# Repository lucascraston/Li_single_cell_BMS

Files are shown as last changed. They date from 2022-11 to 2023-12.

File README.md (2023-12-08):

# Li_single_cell_BMS

<p>
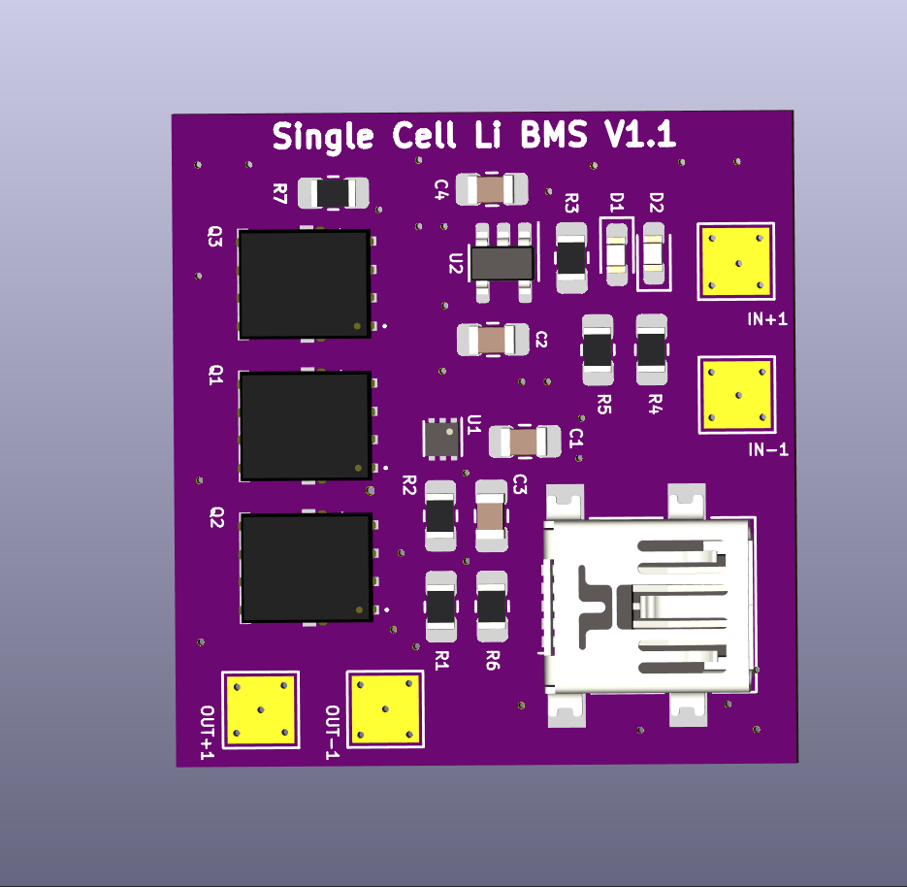
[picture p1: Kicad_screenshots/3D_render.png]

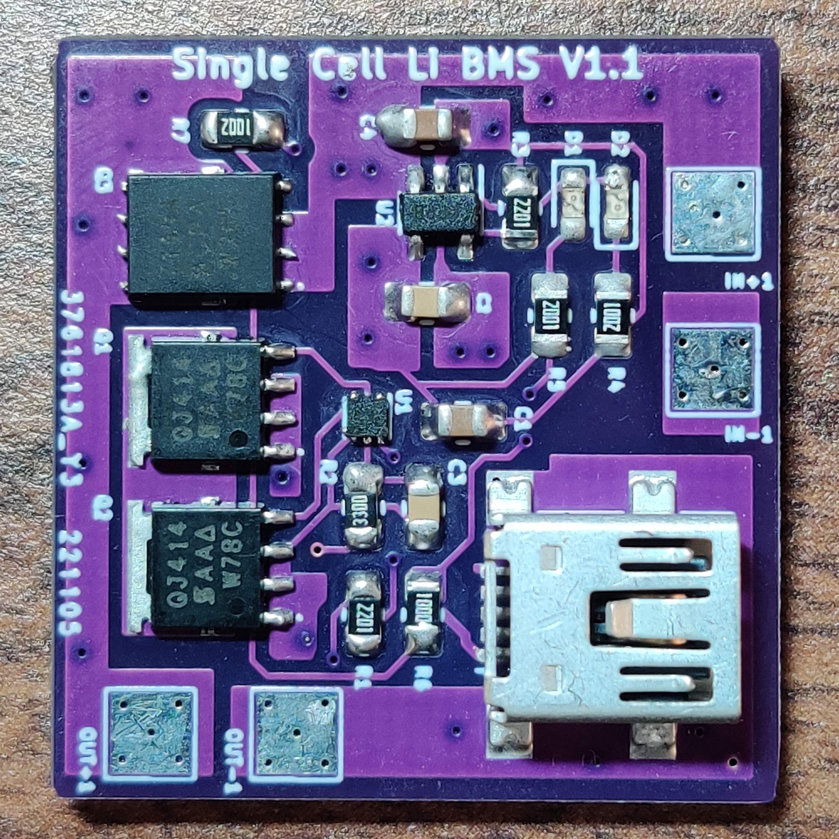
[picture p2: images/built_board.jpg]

</p>
<p>
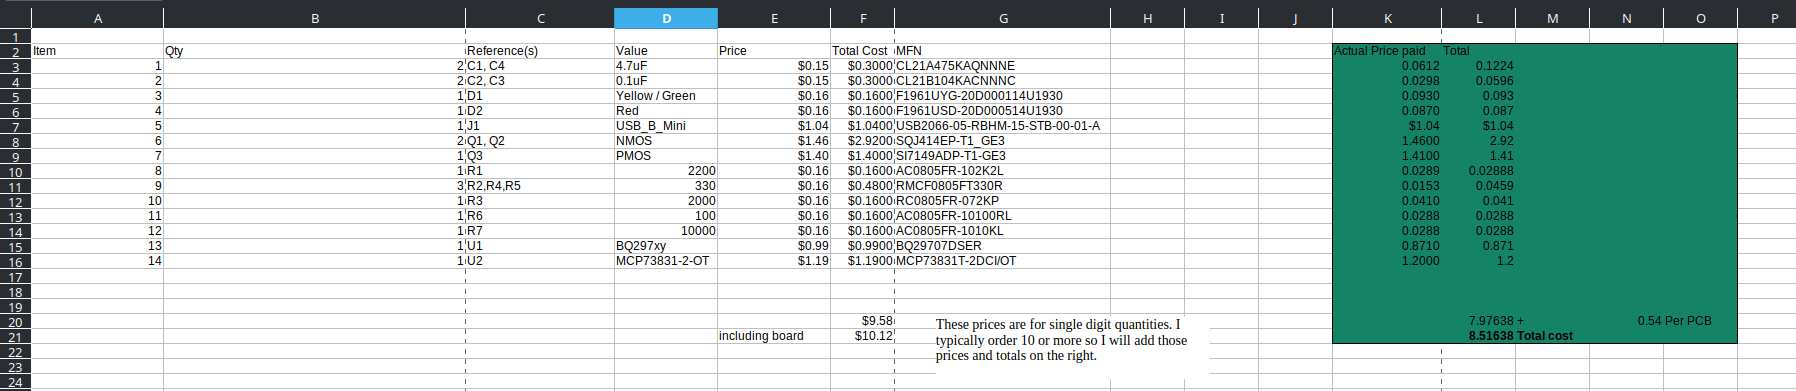
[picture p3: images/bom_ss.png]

</p>
 -This is a Battery Management System (BMS) for a single cell Li-ion or Li-Po battery. I am currently on version 1 of this design, the PCB has been ordered along with the parts and I will assemble and test it when everything arrives.

-I will be adding a BOM for this build, along with a breakdown of the price per component and the total cost to manufactur each board.

-I will also be performing thorough tests on the board to verify its functionilty and I will record the results to upload them. To accompany the tests, I am aiming to complete a Worst Case Circuit Analysis (WCCA) of my design BEFORE I assemble and test. This will help me with determining the expected operating region for each part to ensure I meet my requirments, and to ensure I am within the manufacturers limits.

**A relatively minor mistake was made on the schematic side, which translated into a larger mistake on the PCB.... I will post the updated schematic, maybe you can spot the difference? Anyways, the error would make the charge over current part of the circuit usless, which is was already because the limit is set to over 2.5A, and my charge IC can only do 0.5A. Either way, it is still a mistake, so I am going to fix it in the CAD software and either order another set of PCBs, or mod the ones I already ordered....TBD.**
# Tests to perform:
- [ ] Verify discharge overcurrent and short circuit functionality (Based off N-channel MOSFETs Rds-ON)
- [ ] Test P-channel MOSFET load switch when 5V is applied
- [ ] Verify charge current (Based off resistor choice)
- [ ] verify UVP & OVP charge parameters of charger IC (Based off individual IC)
- [ ] Test charge overcurrent value (The battery should never reach this charge current based on IC choice, use lab PSU)
- [ ] Verify  OVP & UVP parameters of protection IC (Based off individual IC)
# Version 1 Features:
- 0-500 mA charging rate
- Over voltage charge protection: OVP = 4.28V 
- Under voltage discharge protection: UVP = 2.8V 
- Over current discharge protection: OCD = 0.09V (Vss to V-)
- Over current charge protection: OCC = -0.09V (Vss to V-)
- Short circuit protection: SCD = 0.3V
- Load disconnects when charging
- Charging and fully charged LED status indicator
- USB mini B receptacle for charging

# Improvements to be made:
- [ ] 5V boost and 3.3V LDO output rails
- [ ] Go from 2 layer to 4 layer board
- [ ] Onboard battery percentage / status indicator. Maybe this is not neccessary if we are interfacing with a MCU?
- [ ] 5M gate to source pull down resistors
- [ ] 5V input pad to charge battery without USB
- [ ] Dual MOSFET array package to reduce size and cost
- [ ] 1W current sense resistor to make the current limit easier to adjust and test

# Build and Testing

The boards arrived and I have built two so far. I have tested them and everything seems to be working. I am hoping to create a document that outlines each test case and records the testing data to share it on here. I would like to create an automated test script for my scope but It would be difficult without a programmabled PSU...one day.

# To be completed
- [ ] WCCA 
- [ ] Testing documentation

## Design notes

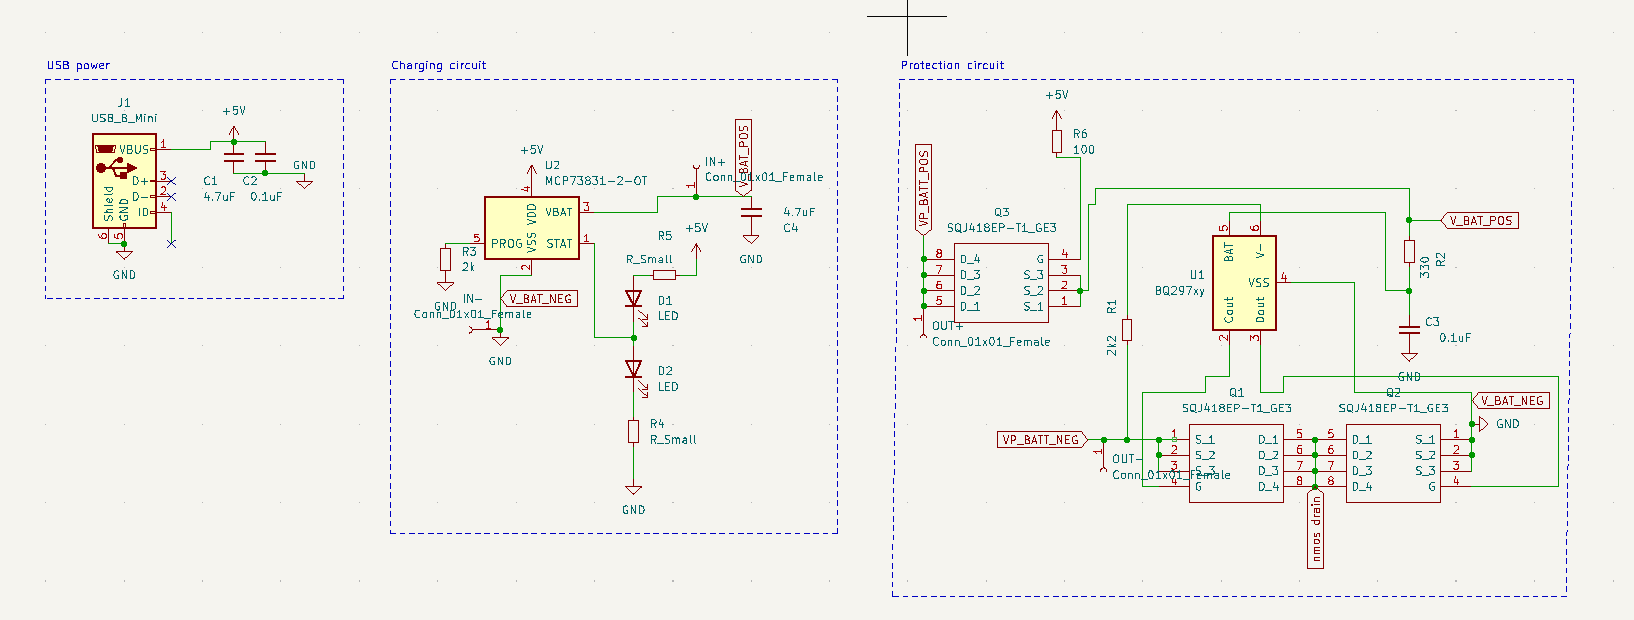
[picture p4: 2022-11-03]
Kicad_screenshots/schematic_diagram_V1.0.png

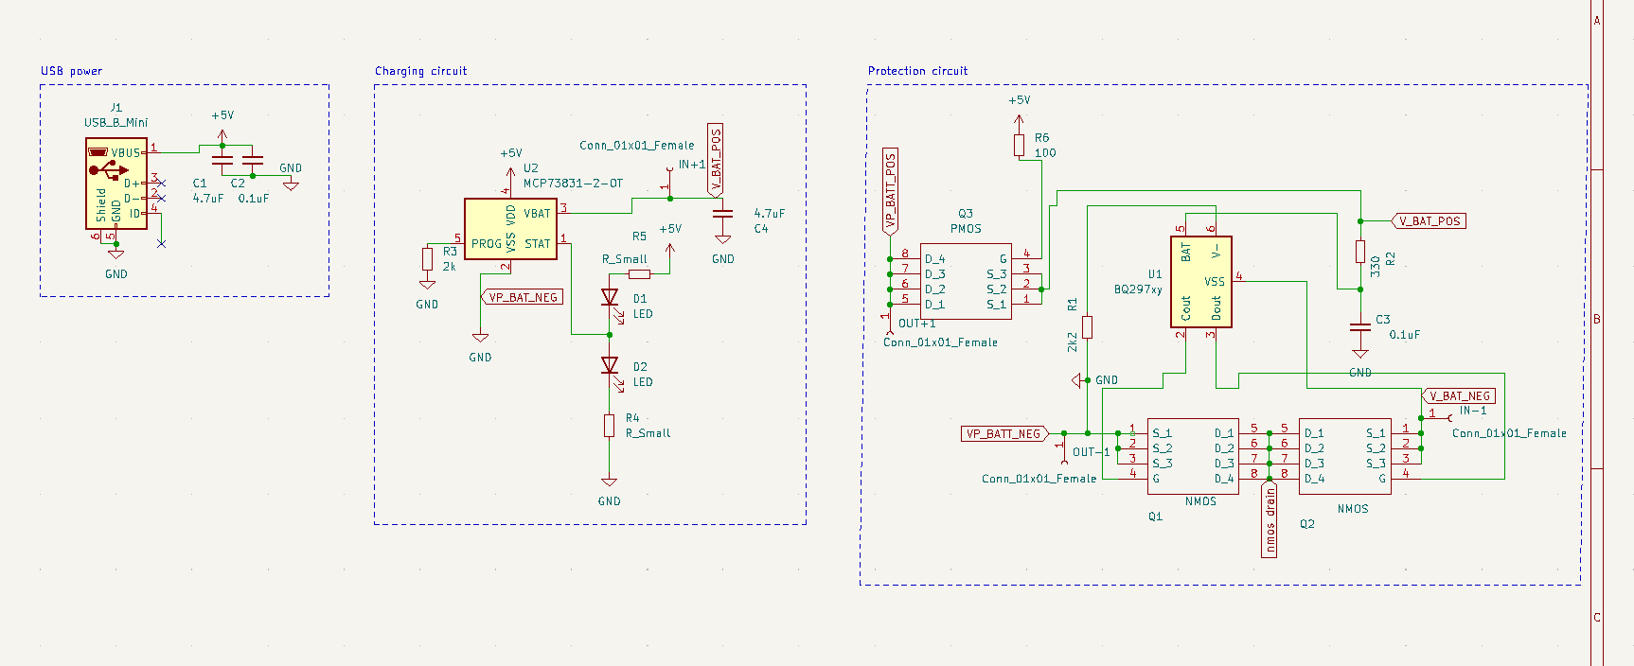
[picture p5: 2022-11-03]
Kicad_screenshots/schematic_diagram_V1.1.png

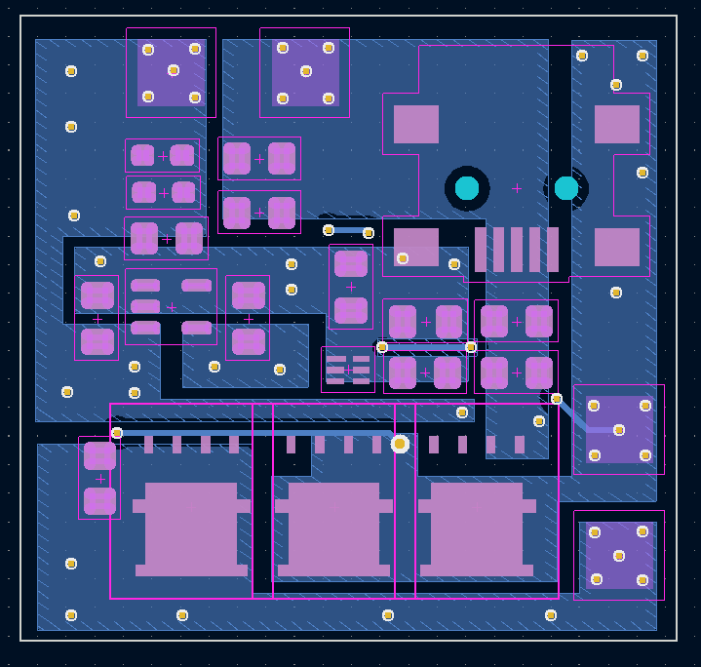
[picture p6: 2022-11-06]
Kicad_screenshots/PCB_bottom_layer.png

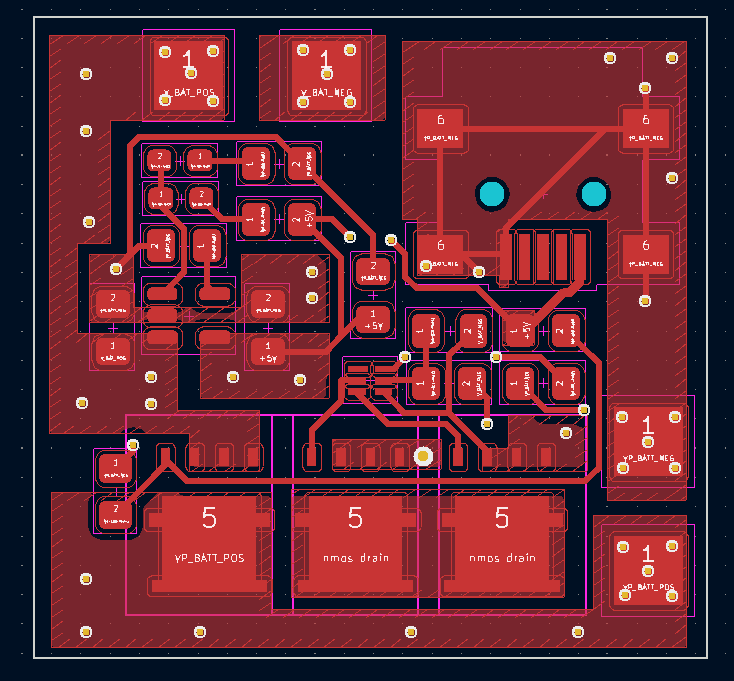
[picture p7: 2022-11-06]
Kicad_screenshots/PCB_top_layer.png

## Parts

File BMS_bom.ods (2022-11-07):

Item | Qty | Reference(s) | Value | Price | Total Cost | MFN | Actual Price paid | Total
1 | 2 | C1, C4 | 4.7uF | $0.15 | $0.3000 | CL21A475KAQNNNE | 0.0612 | 0.1224
2 | 2 | C2, C3 | 0.1uF | $0.15 | $0.3000 | CL21B104KACNNNC | 0.0298 | 0.0596
3 | 1 | D1 | Yellow / Green | $0.16 | $0.1600 | F1961UYG-20D000114U1930 | 0.0930 | 0.093
4 | 1 | D2 | Red | $0.16 | $0.1600 | F1961USD-20D000514U1930 | 0.0870 | 0.087
5 | 1 | J1 | USB_B_Mini | $1.04 | $1.0400 | USB2066-05-RBHM-15-STB-00-01-A | $1.04 | 1.04
6 | 2 | Q1, Q2 | NMOS | $1.46 | $2.9200 | SQJ414EP-T1_GE3 | 1.4600 | 2.92
7 | 1 | Q3 | PMOS | $1.40 | $1.4000 | SI7149ADP-T1-GE3 | 1.4100 | 1.41
8 | 1 | R1 | 2200 | $0.16 | $0.1600 | AC0805FR-102K2L | 0.0289 | 0.02888
9 | 3 | R2,R4,R5 | 330 | $0.16 | $0.4800 | RMCF0805FT330R | 0.0153 | 0.0459
10 | 1 | R3 | 2000 | $0.16 | $0.1600 | RC0805FR-072KP | 0.0410 | 0.041
11 | 1 | R6 | 100 | $0.16 | $0.1600 | AC0805FR-10100RL | 0.0288 | 0.0288
12 | 1 | R7 | 10000 | $0.16 | $0.1600 | AC0805FR-1010KL | 0.0288 | 0.0288
13 | 1 | U1 | BQ297xy | $0.99 | $0.9900 | BQ29707DSER | 0.8710 | 0.871
14 | 1 | U2 | MCP73831-2-OT | $1.19 | $1.1900 | MCP73831T-2DCI/OT | 1.2000 | 1.2
 |  |  |  |  | $9.58 |  |  | 7.97638 | + | 0.54 | Per PCB
 |  |  |  | including board | $10.12 |  |  | 8.51638 | Total cost

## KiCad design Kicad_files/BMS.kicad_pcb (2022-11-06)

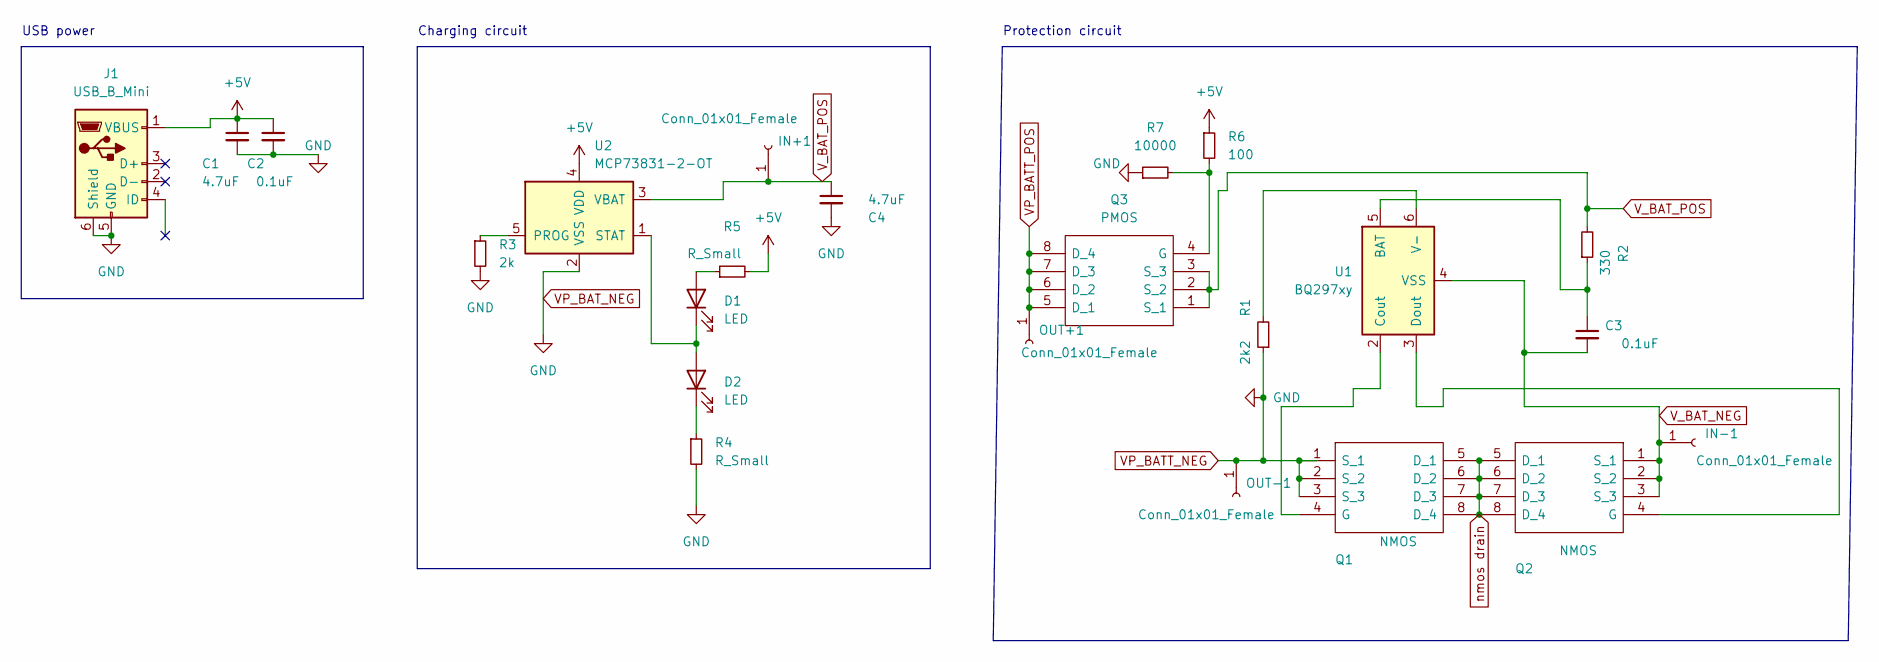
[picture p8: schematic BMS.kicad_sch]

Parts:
C1, C4: 4.7uF; C_0805_2012Metric_Pad1.18x1.45mm_HandSolder
C2, C3: 0.1uF; C_0805_2012Metric_Pad1.18x1.45mm_HandSolder
D1, D2: LED; LED_0603_1608Metric_Pad1.05x0.95mm_HandSolder
IN+1: Conn_01x01_Female; TestPoint_Pad_3.0x3.0mm
IN-1: Conn_01x01_Female; TestPoint_Pad_3.0x3.0mm
J1: USB_B_Mini; USB_Mini-B_Lumberg_2486_01_Horizontal
OUT+1: Conn_01x01_Female; TestPoint_Pad_3.0x3.0mm
OUT-1: Conn_01x01_Female; TestPoint_Pad_3.0x3.0mm
Q1, Q2: NMOS; SQJ418EPT1_GE3; Manufacturer_Part_Number SQJ418EP-T1_GE3; Mouser Part Number 78-SQJ418EP-T1_GE3
Q3: PMOS; SQJ418EPT1_GE3; Manufacturer_Part_Number SQJ418EP-T1_GE3; Mouser Part Number 78-SQJ418EP-T1_GE3
R1: 2k2; R_0805_2012Metric_Pad1.20x1.40mm_HandSolder
R2: 330; R_0805_2012Metric_Pad1.20x1.40mm_HandSolder
R3: 2k; R_0805_2012Metric_Pad1.20x1.40mm_HandSolder
R4, R5: R_Small; R_0805_2012Metric_Pad1.20x1.40mm_HandSolder
R6: 100; R_0805_2012Metric_Pad1.20x1.40mm_HandSolder
R7: 10000; R_0805_2012Metric_Pad1.20x1.40mm_HandSolder
U1: BQ297xy; WSON-6_1.5x1.5mm_P0.5mm
U2: MCP73831-2-OT; SOT-23-5

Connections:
+5V: C1.1, C2.1, J1.1 (VBUS), R5.2, R6.1, U2.4 (VDD)
unnamed: C3.1, R2.1, U1.5 (BAT)
unnamed: D1.1 (K), D2.2 (A), U2.1 (STAT)
unnamed: D1.2 (A), R5.1
unnamed: D2.1 (K), R4.1
unnamed: Q1.4 (G), U1.2 (Cout)
unnamed: Q2.4 (G), U1.3 (Dout)
unnamed: Q3.4 (G), R6.2, R7.2
unnamed: R1.2, U1.6 (V-)
unnamed: R3.1, U2.5 (PROG)
VP_BATT_NEG: C1.2, C2.2, C4.2, J1.5 (GND), J1.6 (Shield), OUT-1.1, Q1.1 (S_1), Q1.2 (S_2), Q1.3 (S_3), R1.1, R3.2, R4.2, R7.1, U2.2 (VSS)
VP_BATT_POS: OUT+1.1, Q3.5 (D_1), Q3.6 (D_2), Q3.7 (D_3), Q3.8 (D_4)
V_BAT_NEG: C3.2, IN-1.1, Q2.1 (S_1), Q2.2 (S_2), Q2.3 (S_3), U1.4 (VSS)
V_BAT_POS: C4.1, IN+1.1, Q3.1 (S_1), Q3.2 (S_2), Q3.3 (S_3), R2.2, U2.3 (VBAT)
nmos drain: Q1.5 (D_1), Q1.6 (D_2), Q1.7 (D_3), Q1.8 (D_4), Q2.5 (D_1), Q2.6 (D_2), Q2.7 (D_3), Q2.8 (D_4)

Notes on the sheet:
USB power
Charging circuit
Protection circuit

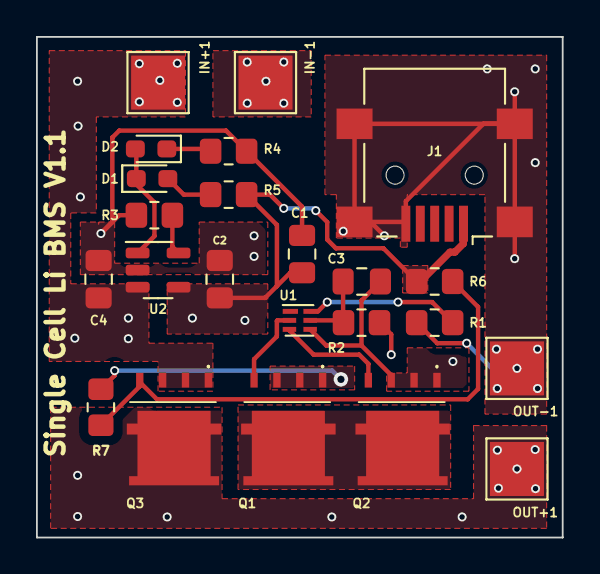
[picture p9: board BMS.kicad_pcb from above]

Board: 2 copper layers, 29.2 x 27.8 mm, 23 parts (0 on the bottom side), 15 nets.

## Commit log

2022-11-02 added screenshots of pcb,scheme, and 3d view
2022-11-03 updated schematic image
2022-11-03 added updated schematic image
2022-11-06 updated kicad images
2022-11-06 new kicad files to reflect v1.1 changes
    [BMS.kicad_pcb, BMS.kicad_sch]
2022-11-06 new gerbers for new v1.1 board
2022-11-07 Added bom part list and cost
    [BMS_bom.ods]
2023-12-08 added bill of materials to readme
